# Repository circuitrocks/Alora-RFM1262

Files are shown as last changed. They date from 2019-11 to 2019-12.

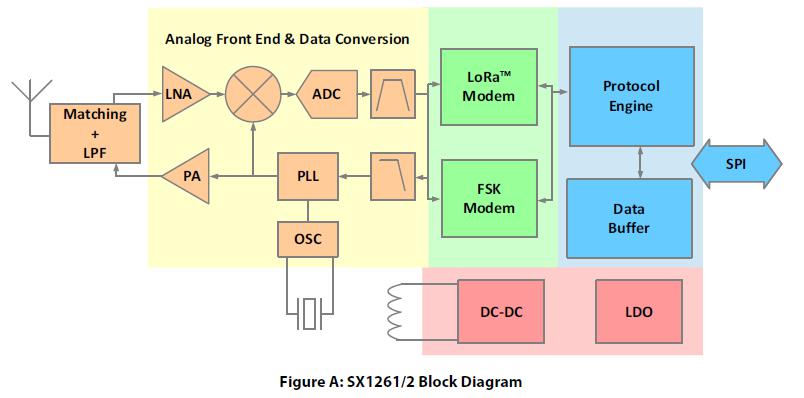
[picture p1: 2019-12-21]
Alora-RFM1262-Productsheet_html_1c7b20d6.jpg

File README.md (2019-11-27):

# Alora-RFM1262 support files for the Alora RFM1262 boards.    
This repository contains the HW and SW support files for the [Circuitrocks Alora RFM1262](https://circuit.rocks/lora) board. 

The board is compatible with the [Adafruit Feather specifications](https://learn.adafruit.com/adafruit-feather?view=all). But it is tested only with the [Adafruit Feather HUZZAH ESP8266](https://circuit.rocks/wifi-feather-huzzah-esp8266-adafruit.html) and the [Adafruit HUZZAH32 ESP32](https://circuit.rocks/huzzah32-esp32-feather-board-adafruit.html) Feathers.

## Hardware
[Eagle format schematic and PCB files](https://github.com/circuitrocks/Alora-RFM1262/tree/master/Hardware/Eagle)    
[Schematic as PDF file](https://github.com/circuitrocks/Alora-RFM1262/tree/master/Hardware)    
[3D files of the board in Autodesk Fusion 360 and STEP format](https://github.com/circuitrocks/Alora-RFM1262/tree/master/Hardware/3D)    

## Software
At the moment there are two Arduino libraries available that support the Semtech SX1262 chips.
- [RadioLib](https://github.com/jgromes/RadioLib) by Jan Gromes
- [SX126x-Arduino](https://github.com/beegee-tokyo/SX126x-Arduino) by Bernd Giesecke

Please check the ArduinoIDE or PlatformIO documentation how to install the libraries.

The first one is easier to use and supports most Arduino HW platforms.
The second one is more complicated and supports only ESP8266, ESP32 and nRF52 HW platforms. **_But it supports LoRaWan_** and it has a working example for a **_single channel LoRaWan gateway_**.

It is recommended to use the RadioLib library if you just want to do simple LoRa communication. But if you want to connect your Alora SX1262 module to LoRaWan you should choose the SX126x-Arduino library.

Examples for both libraries can be found in the folders [Using_SX1262x_Arduino](https://github.com/circuitrocks/Alora-RFM1262/tree/master/Software/Using_SX126x_Arduino) and [Using_RadioLib](https://github.com/circuitrocks/Alora-RFM1262/tree/master/Software/Using_RadioLib).    
Most examples are available for ArduinoIDE and PlatformIO. But if you are serious in programming, I strongly recommend you switch to PlatformIO as your development IDE.

- RadioLib examples
  - [RFM1262-PING](https://github.com/circuitrocks/Alora-RFM1262/tree/master/Software/Using_RadioLib/ArduinoIDE/RFM1262-PING) and [RFM1262-PONG](https://github.com/circuitrocks/Alora-RFM1262/tree/master/Software/Using_RadioLib/ArduinoIDE/RFM1262-PONG) are simple communication examples between two LoRa nodes using the RadioLib library. These examples are for ArduinoIDE.
  - [RFM1262-PING](https://github.com/circuitrocks/Alora-RFM1262/tree/master/Software/Using_RadioLib/PlatformIO/RFM1262-PING) and [RFM1262-PONG](https://github.com/circuitrocks/Alora-RFM1262/tree/master/Software/Using_RadioLib/PlatformIO/RFM1262-PONG) are simple communication examples between two LoRa nodes using the RadioLib library. These examples are for PlatformIO.
- SX126x-Arduino examples
  - [PingPong](https://github.com/circuitrocks/Alora-RFM1262/tree/master/Software/Using_SX126x_Arduino/ArduinoIDE/PingPong) is a simple communication example between two LoRa nodes using the SX126x_Arduino library with ArduinoIDE
  - [LoRaWanPio](https://github.com/circuitrocks/Alora-RFM1262/tree/master/Software/Using_SX126x_Arduino/PlatformIO/LoRaWanPio) is an example for a LoRaWan node.
  - [SX1262-SC-GW](https://github.com/circuitrocks/Alora-RFM1262/tree/master/Software/Using_SX126x_Arduino/PlatformIO/SX1262-SC-GW) is a single channel LoRaWan gateway. The code is based on the [ESP-1ch-Gateway-v6.0](https://github.com/things4u/ESP-1ch-Gateway-v6.0) single channel LoRaWan gateway. It was ported from from Semtech SX127x to Semttech SX1262 LoRa chips. More information can be found in the [readme](https://github.com/circuitrocks/Alora-RFM1262/blob/master/Software/Using_SX126x_Arduino/PlatformIO/SX1262-SC-GW/README.md) for this application.

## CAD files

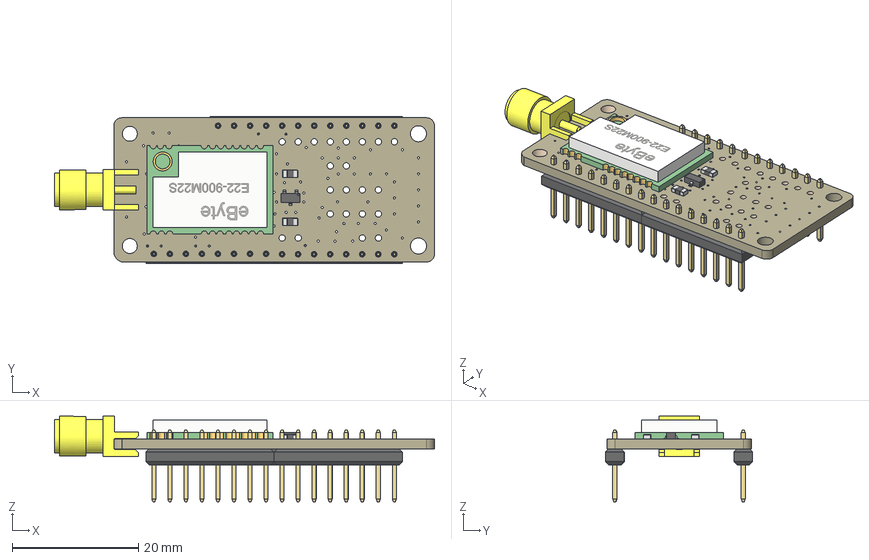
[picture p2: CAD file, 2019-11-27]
Hardware/3D/RFM1262 v5.step
60.2 x 23.4 x 13.6 mm
Board
E22-900M22S
S9013
10K
10K_1
U.FL/SMA
8p-2.54
8p-2.54_1
6p-2.54
6p-2.54_1

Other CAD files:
Hardware/3D/RFM1262 v5.f3d

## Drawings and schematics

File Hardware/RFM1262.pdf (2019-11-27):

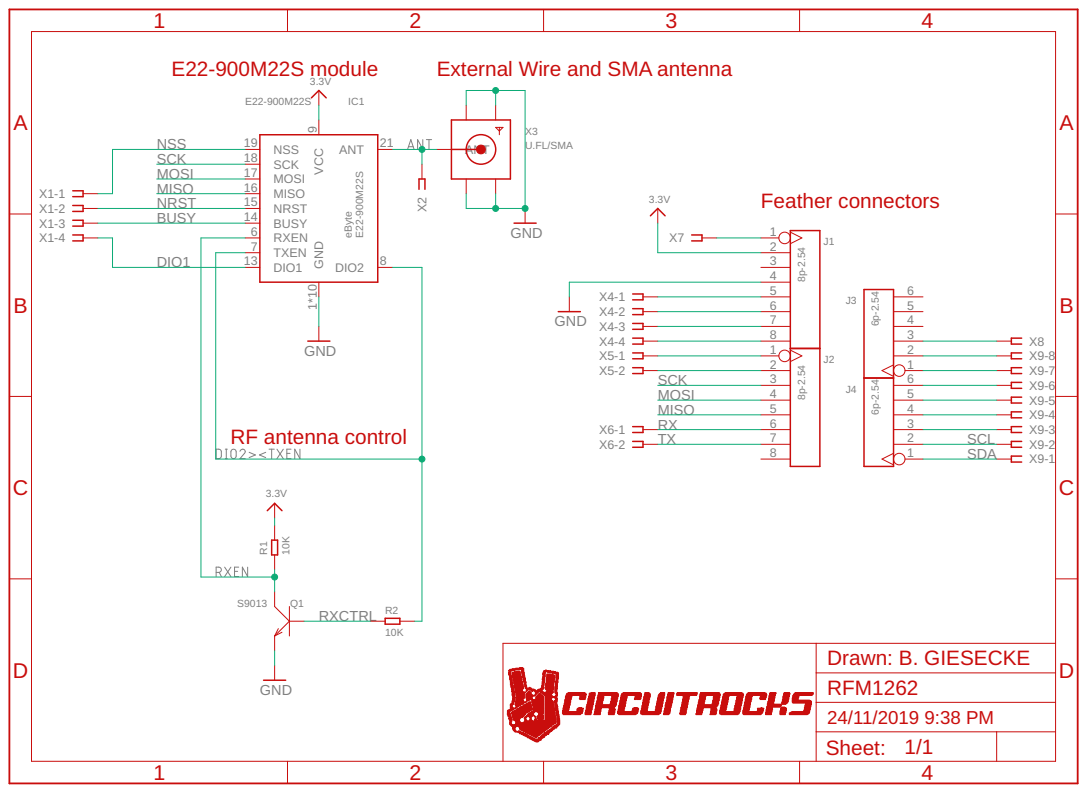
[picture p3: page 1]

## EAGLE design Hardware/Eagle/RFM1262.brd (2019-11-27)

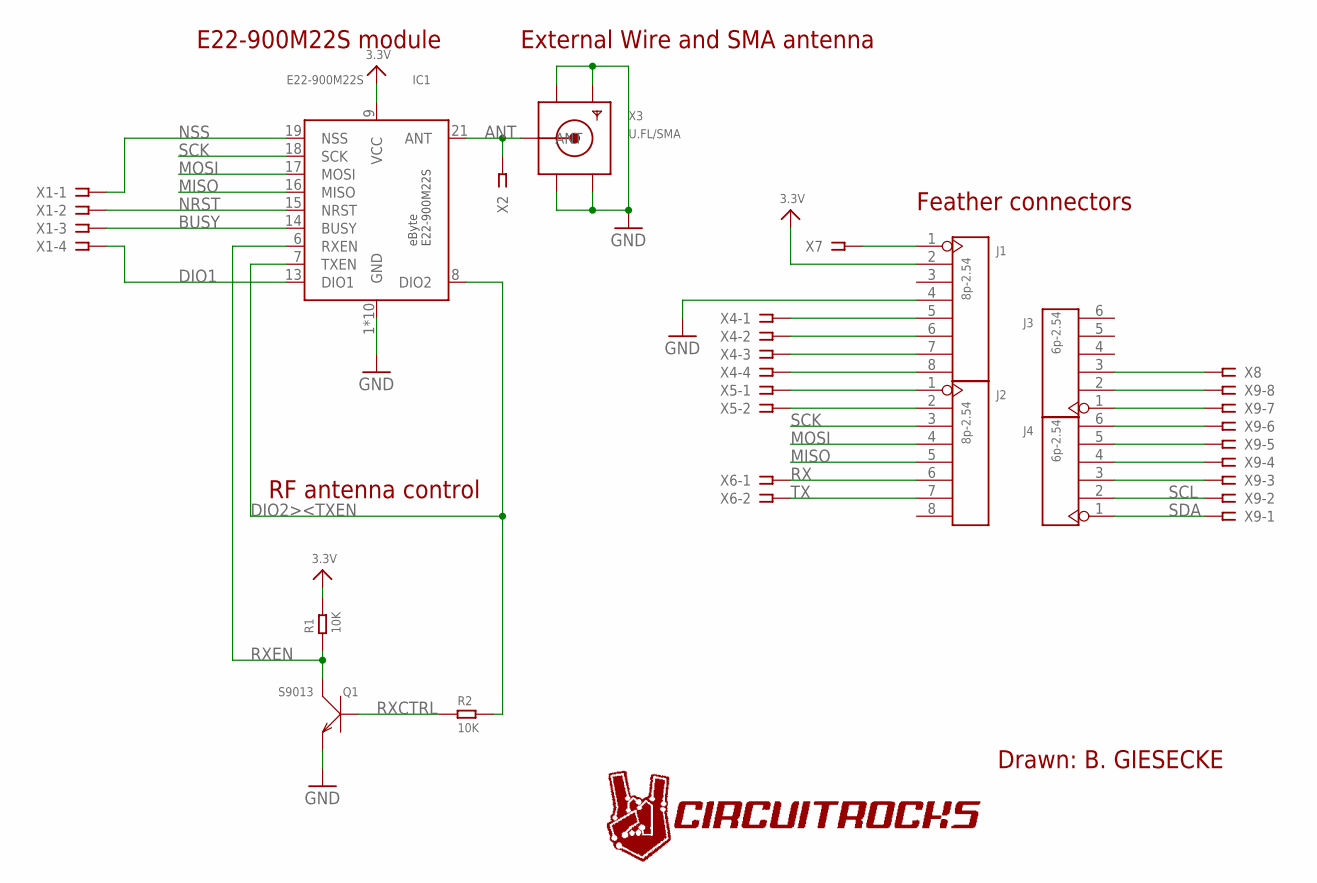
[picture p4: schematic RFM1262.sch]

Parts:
IC1: E22-900M22S
J1, J2: 8p-2.54; H8-2.54
J3, J4: 6p-2.54; H6-2.54
Q1: S9013; SOT-23
R1, R2: 10K; R0805
X1, X4: SSW-104-02-G-S
X2, X7, X8: SSW-101-02-G-S
X3: U.FL/SMA; SMA_EDGELAUNCH_UFL
X5, X6: SSW-102-02-G-S
X9: SSW-108-02-G-S

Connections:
3.3V: IC1.9 (VCC), J1.2, R1.2
ANT: IC1.21 (ANT), X2.1, X3.P (ANT)
BUSY: IC1.14 (BUSY), X1.3
DIO1: IC1.13 (DIO1), X1.4
DIO2><TXEN: IC1.7 (TXEN), IC1.8 (DIO2), R2.2
GND: IC1.1 (GND), IC1.2 (GND), IC1.3 (GND), IC1.4 (GND), IC1.5 (GND), IC1.10 (GND), IC1.11 (GND), IC1.12 (GND), IC1.20 (GND), IC1.22 (GND), J1.4, Q1.2 (E), X3.GND@1 (GND1), X3.GND@2 (GND2), X3.GND@3 (GND3), X3.GND@4 (GND4)
MISO: IC1.16 (MISO), J2.5
MOSI: IC1.17 (MOSI), J2.4
unnamed: J1.1, X7.1
unnamed: J3.3, X8.1
unnamed: J1.5, X4.1
unnamed: J1.6, X4.2
unnamed: J1.7, X4.3
unnamed: J1.8, X4.4
unnamed: J2.1, X5.1
unnamed: J2.2, X5.2
unnamed: J3.2, X9.8
unnamed: J3.1, X9.7
unnamed: J4.6, X9.6
unnamed: J4.5, X9.5
unnamed: J4.4, X9.4
unnamed: J4.3, X9.3
NRST: IC1.15 (NRST), X1.2
NSS: IC1.19 (NSS), X1.1
RX: J2.6, X6.1
RXCTRL: Q1.1 (B), R2.1
RXEN: IC1.6 (RXEN), Q1.3 (C), R1.1
SCK: IC1.18 (SCK), J2.3
SCL: J4.2, X9.2
SDA: J4.1, X9.1
TX: J2.7, X6.2

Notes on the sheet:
Drawn: B. GIESECKE
E22-900M22S module
External Wire and SMA antenna
Feather connectors
RF antenna control

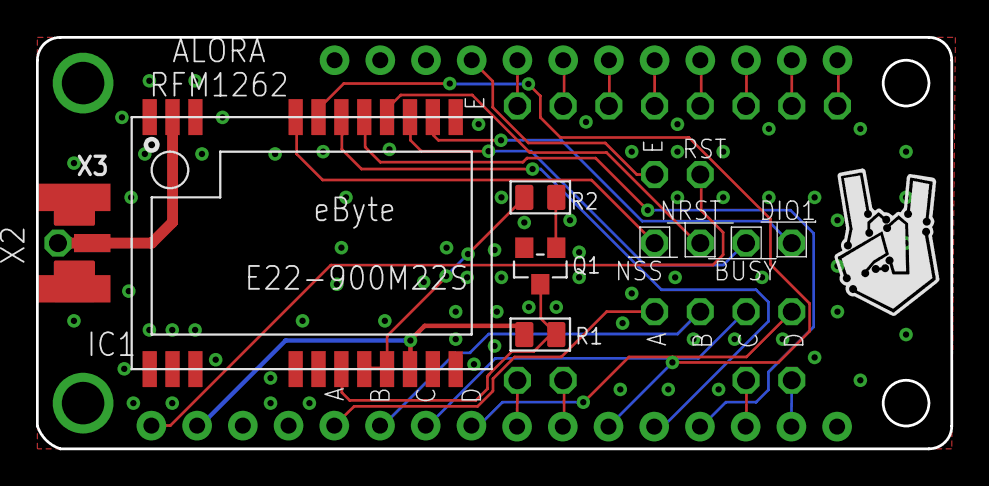
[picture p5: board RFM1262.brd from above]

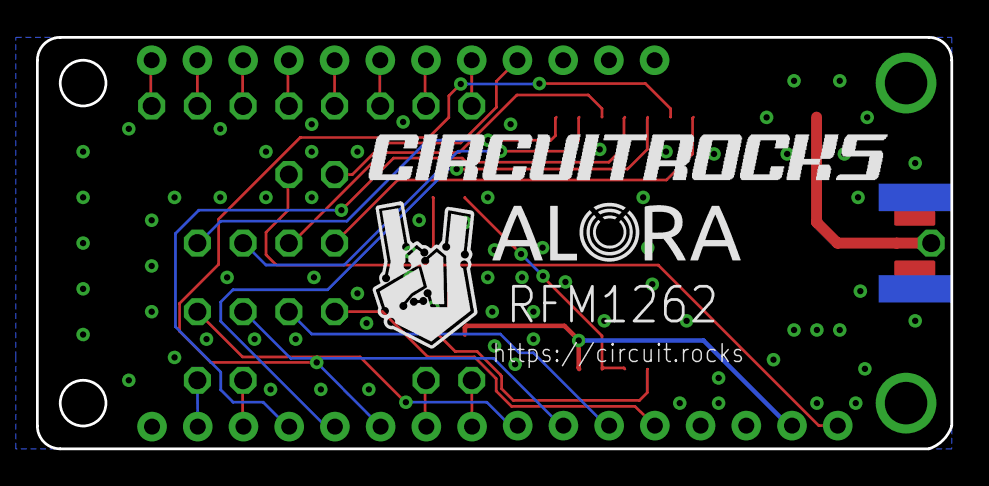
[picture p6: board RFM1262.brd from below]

Board: 2 copper layers, 50.8 x 22.9 mm, 17 parts (4 on the bottom side), 31 nets.

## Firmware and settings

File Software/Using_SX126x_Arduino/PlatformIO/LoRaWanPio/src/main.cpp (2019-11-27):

#include <Arduino.h>

#include <LoRaWan-Arduino.h>
#include <SPI.h>
#include <Ticker.h>
#ifdef ESP32
#include <WiFi.h>
#include <WiFiMulti.h>
#include <ESPmDNS.h>
#include <WiFiUdp.h>
#include <ArduinoOTA.h>
WiFiMulti wifiMulti;
#endif
#ifdef ESP8266
#include <ESP8266WiFi.h>
#include <ESP8266WiFiMulti.h>
#include <ESP8266mDNS.h>
#include <WiFiUdp.h>
#include <ArduinoOTA.h>
ESP8266WiFiMulti wifiMulti;
#endif

// #define SCHED_MAX_EVENT_DATA_SIZE APP_TIMER_SCHED_EVENT_DATA_SIZE /**< Maximum size of scheduler events. */
// #define SCHED_QUEUE_SIZE 60										  /**< Maximum number of events in the scheduler queue. */

#define LORAWAN_ADR_ON 1  /**< LoRaWAN Adaptive Data Rate enabled (the end-device should be static here). */
#define LORAWAN_ADR_OFF 0 /**< LoRaWAN Adaptive Data Rate disabled. */

#define LORAWAN_APP_DATA_BUFF_SIZE 256  /**< Size of the data to be transmitted. */
#define LORAWAN_APP_TX_DUTYCYCLE 30000 /**< Defines the application data transmission duty cycle. 30s, value in [ms]. */
#define APP_TX_DUTYCYCLE_RND 1000	  /**< Defines a random delay for application data transmission duty cycle. 1s, value in [ms]. */
#define JOINREQ_NBTRIALS 3			   /**< Number of trials for the join request. */

hw_config hwConfig;

#ifdef ESP32
#ifdef RED_BOARD
// ESP32 Elecrow Red board - SX126x pin configuration
int PIN_LORA_RESET = 4;  // LORA RESET
int PIN_LORA_NSS = 5;	// LORA SPI CS
int PIN_LORA_SCLK = 18;  // LORA SPI CLK
int PIN_LORA_MISO = 19;  // LORA SPI MISO
int PIN_LORA_DIO_1 = 26; // LORA DIO_1
int PIN_LORA_BUSY = 25;  // LORA SPI BUSY
int PIN_LORA_MOSI = 23;  // LORA SPI MOSI
uint8_t nodeDeviceEUI[8] = {0x00, 0x95, 0x64, 0x1F, 0xDA, 0x91, 0x19, 0x0B};
uint8_t nodeAppEUI[8] = {0x70, 0xB3, 0xD5, 0x7E, 0xD0, 0x02, 0x01, 0xE1};
// Only needed for OOTA registration
// uint8_t nodeAppKey[16] = {0x07, 0xC0, 0x82, 0x0C, 0x30, 0xB9, 0x08, 0x70, 0x0C, 0x0F, 0x70, 0x06, 0x00, 0xB0, 0xBE, 0x09};
uint32_t nodeDevAddr = 0x260211CE;
uint8_t nodeNwsKey[16] = {0x71, 0x6E, 0xB7, 0x65, 0x90, 0x60, 0x8F, 0xEB, 0x50, 0x24, 0xF9, 0x98, 0x31, 0x29, 0x82, 0xC8};
uint8_t nodeAppsKey[16] = {0x0B, 0x94, 0x60, 0x10, 0x8C, 0x41, 0x3C, 0x7C, 0xF8, 0xC7, 0x99, 0x14, 0x27, 0x90, 0x96, 0x92};
#define LED_ON LOW
#define LED_OFF HIGH
#elif defined WROVER_BOARD
// ESP32 Wrover black board - SX126x pin configuration
int PIN_LORA_RESET = 4;  // LORA RESET
int PIN_LORA_NSS = 5;	// LORA SPI CS
int PIN_LORA_SCLK = 18;  // LORA SPI CLK
int PIN_LORA_MISO = 19;  // LORA SPI MISO
int PIN_LORA_DIO_1 = 26; // LORA DIO_1
int PIN_LORA_BUSY = 25;  // LORA SPI BUSY
int PIN_LORA_MOSI = 23;  // LORA SPI MOSI
uint8_t nodeDeviceEUI[8] = {0x00, 0x20, 0x45, 0xB4, 0xDF, 0xF7, 0x2A, 0x33};
uint8_t nodeAppEUI[8] = {0x70, 0xB3, 0xD5, 0x7E, 0xD0, 0x02, 0x01, 0xE1};
// Only needed for OOTA registration
// uint8_t nodeAppKey[16] = {0x07, 0xC0, 0x82, 0x0C, 0x30, 0xB9, 0x08, 0x70, 0x0C, 0x0F, 0x70, 0x06, 0x00, 0xB0, 0xBE, 0x09};
uint32_t nodeDevAddr = 0x26021040;
uint8_t nodeNwsKey[16] = {0x52, 0x71, 0x0C, 0x47, 0x98, 0xD8, 0xE3, 0xE1, 0x7A, 0x40, 0x4B, 0x2C, 0x5A, 0x74, 0x00, 0xB7};
uint8_t nodeAppsKey[16] = { 0xB4, 0x0F, 0xCD, 0xD2, 0x5E, 0x2B, 0x4D, 0xBE, 0xD9, 0x92, 0x40, 0x0E, 0x6F, 0x65, 0x91, 0xB9 };
#define LED_ON LOW
#define LED_OFF HIGH
#else
// ESP32 Feather - SX126x pin configuration
int PIN_LORA_RESET = 32; //16; // LORA RESET
int PIN_LORA_DIO_1 = 14; //14; // LORA DIO_1
int PIN_LORA_BUSY = 27;  //33; // LORA SPI BUSY
int PIN_LORA_NSS = 33;   //27; // LORA SPI CS
int PIN_LORA_SCLK = 5;   // LORA SPI CLK
int PIN_LORA_MISO = 19;  // LORA SPI MISO
int PIN_LORA_MOSI = 18;  // LORA SPI MOSI
uint8_t nodeDeviceEUI[8] = {0x00, 0xE6, 0xBF, 0xFF, 0xCD, 0x42, 0x4C, 0x2B};
uint8_t nodeAppEUI[8] = {0x70, 0xB3, 0xD5, 0x7E, 0xD0, 0x02, 0x01, 0xE1};
// Only needed for OOTA registration
// uint8_t nodeAppKey[16] = {0x07, 0xC0, 0x82, 0x0C, 0x30, 0xB9, 0x08, 0x70, 0x0C, 0x0F, 0x70, 0x06, 0x00, 0xB0, 0xBE, 0x09};
uint32_t nodeDevAddr = 0x26021C92;
uint8_t nodeNwsKey[16] = {0x06, 0x52, 0x24, 0x82, 0x79, 0x75, 0xD1, 0x95, 0xF8, 0xED, 0x21, 0x84, 0x0D, 0x8A, 0xC6, 0xFD};
uint8_t nodeAppsKey[16] = {0x68, 0xE8, 0xD9, 0xC6, 0xC7, 0x79, 0x8F, 0x22, 0x2B, 0x91, 0x7E, 0xF1, 0x94, 0x34, 0x7B, 0xD9};
#define LED_ON HIGH
#define LED_OFF LOW
#endif
#endif
#ifdef ESP8266
// ESP8266 Feather - SX126x pin configuration
int PIN_LORA_RESET = -1; // 16;  // LORA RESET NOT CONNECTED !
int PIN_LORA_DIO_1 = 15; // 5;   // LORA DIO_1
int PIN_LORA_BUSY = 16; // 4;	// LORA SPI BUSY
int PIN_LORA_NSS = 0; // 15;	// LORA SPI CS
int PIN_LORA_SCLK = SCK;  // 14; // LORA SPI CLK
int PIN_LORA_MISO = MISO; // 12; // LORA SPI MISO
int PIN_LORA_MOSI = MOSI; // 13; // LORA SPI MOSI
uint8_t nodeDeviceEUI[8] = {0x00, 0xD0, 0x53, 0xDE, 0x91, 0xEF, 0xC1, 0x95};
uint8_t nodeAppEUI[8] = {0x70, 0xB3, 0xD5, 0x7E, 0xD0, 0x02, 0x01, 0xE1};
// Only needed for OOTA registration
// uint8_t nodeAppKey[16] = {0x07, 0xC0, 0x82, 0x0C, 0x30, 0xB9, 0x08, 0x70, 0x0C, 0x0F, 0x70, 0x06, 0x00, 0xB0, 0xBE, 0x09};
uint32_t nodeDevAddr = 0x260214FE;
uint8_t nodeNwsKey[16] = {0x66, 0xCE, 0xD5, 0xCD, 0x2A, 0x30, 0xC7, 0x1F, 0x34, 0x07, 0xB2, 0x58, 0x7D, 0x09, 0x64, 0x66};
uint8_t nodeAppsKey[16] = {0xAF, 0x6C, 0x9A, 0x5B, 0x08, 0x64, 0x5B, 0x1E, 0x9B, 0xAB, 0x92, 0x66, 0x3E, 0xA5, 0x43, 0x42};
#define LED_ON LOW
#define LED_OFF HIGH
#endif

#if !defined(ESP32) && !defined(ESP8266)
#error "Board not supported"
#endif

// Foward declaration
static void lorawan_has_joined_handler(void);
static void lorawan_rx_handler(lmh_app_data_t *app_data);
static void lorawan_confirm_class_handler(DeviceClass_t Class);
static void send_lora_frame(void);
static uint32_t timers_init(void);

// APP_TIMER_DEF(lora_tx_timer_id);                                              ///< LoRa tranfer timer instance.
TimerEvent_t appTimer;														  ///< LoRa tranfer timer instance.
static uint8_t m_lora_app_data_buffer[LORAWAN_APP_DATA_BUFF_SIZE];			  ///< Lora user application data buffer.
static lmh_app_data_t m_lora_app_data = {m_lora_app_data_buffer, 0, 0, 0, 0}; ///< Lora user application data structure.

/**@brief Structure containing LoRaWan parameters, needed for lmh_init()
 */
static lmh_param_t lora_param_init = {LORAWAN_ADR_OFF, DR_3, LORAWAN_PUBLIC_NETWORK, JOINREQ_NBTRIALS, LORAWAN_DEFAULT_TX_POWER};
// DR_8
// LORAWAN_DEFAULT_DATARATE
/**@brief Structure containing LoRaWan callback functions, needed for lmh_init()
*/
static lmh_callback_t lora_callbacks = {BoardGetBatteryLevel, BoardGetUniqueId, BoardGetRandomSeed,
										lorawan_rx_handler, lorawan_has_joined_handler, lorawan_confirm_class_handler};

// Check if the board has an LED port defined
#ifndef LED_BUILTIN
#ifdef ESP32
#ifdef RED_BOARD
#define LED_BUILTIN 16
#else
#define LED_BUILTIN 13
#endif
#endif
#ifdef ESP8266
#define LED_BUILTIN 0
#endif
#endif

int32_t chipTemp = 0;

Ticker ledTicker;

bool wifiFirstConnect = true;

/**@brief Setup function
 */
void ledOff(void)
{
	digitalWrite(LED_BUILTIN, LED_OFF);
}

/**@brief Setup function
 */
void setup()
{
	pinMode(LED_BUILTIN, OUTPUT);
	digitalWrite(LED_BUILTIN, LED_OFF);

	// Define the HW configuration between MCU and SX126x
	hwConfig.CHIP_TYPE = SX1262_CHIP;		  // Example uses an eByte E22 module with an SX1262
	hwConfig.PIN_LORA_RESET = PIN_LORA_RESET; // LORA RESET
	hwConfig.PIN_LORA_NSS = PIN_LORA_NSS;	 // LORA SPI CS
	hwConfig.PIN_LORA_SCLK = PIN_LORA_SCLK;   // LORA SPI CLK
	hwConfig.PIN_LORA_MISO = PIN_LORA_MISO;   // LORA SPI MISO
	hwConfig.PIN_LORA_DIO_1 = PIN_LORA_DIO_1; // LORA DIO_1
	hwConfig.PIN_LORA_BUSY = PIN_LORA_BUSY;   // LORA SPI BUSY
	hwConfig.PIN_LORA_MOSI = PIN_LORA_MOSI;   // LORA SPI MOSI
	hwConfig.RADIO_TXEN = -1;				  // LORA ANTENNA TX ENABLE
	hwConfig.RADIO_RXEN = -1;				  // LORA ANTENNA RX ENABLE
	hwConfig.USE_DIO2_ANT_SWITCH = true;	  // Example uses an CircuitRocks Alora RFM1262 which uses DIO2 pins as antenna control
	hwConfig.USE_DIO3_TCXO = true;			  // Example uses an CircuitRocks Alora RFM1262 which uses DIO3 to control oscillator voltage
	hwConfig.USE_DIO3_ANT_SWITCH = false;	 // Only Insight ISP4520 module uses DIO3 as antenna control

	// Initialize Serial for debug output
	Serial.begin(115200);

	Serial.println("=====================================");
	Serial.println("SX126x LoRaWan test");
	Serial.printf("Node %X\n", nodeDevAddr);
	Serial.println("=====================================");

	// Start WiFi so we can do OTA from here
	wifiMulti.addAP("MHC2", "teresa1963");
	wifiMulti.addAP("MHC", "teresa1963");

	wifiMulti.run();

	// Initialize Scheduler and timer
	uint32_t err_code = timers_init();
	if (err_code != 0)
	{
		Serial.printf("timers_init failed - %d\n", err_code);
	}

	// Initialize LoRa chip.
	err_code = lora_hardware_init(hwConfig);
	if (err_code != 0)
	{
		Serial.printf("lora_hardware_init failed - %d\n", err_code);
	}

	// Setup the EUIs and Keys
	lmh_setDevEui(nodeDeviceEUI);
	lmh_setAppEui(nodeAppEUI);
	// lmh_setAppKey(nodeAppKey); // Only needed for OOTA registration
	lmh_setNwkSKey(nodeNwsKey);
	lmh_setAppSKey(nodeAppsKey);
	lmh_setDevAddr(nodeDevAddr);

	// #ifndef RED_BOARD
	// 	// Setup connection to a single channel gateway
	// 	lmh_setSingleChannelGateway(0, DR_3);
	// #endif

	// Initialize LoRaWan
	err_code = lmh_init(&lora_callbacks, lora_param_init);
	if (err_code != 0)
	{
		Serial.printf("lmh_init failed - %d\n", err_code);
	}

	// For some regions we might need to define the sub band the gateway is listening to
	/// \todo This is for Dragino LPS8 gateway. How about other gateways???
	if (!lmh_setSubBandChannels(1))
	{
		Serial.println("lmh_setSubBandChannels failed. Wrong sub band requested?");
	}

	// Start Join procedure
	lmh_join();
}

/**@brief Main loop
 */
void loop()
{
	// Handle Radio events
	Radio.IrqProcess();

#ifndef ESP8266
	if (wifiFirstConnect && WiFi.isConnected())
	{
		// Start OTA now
		wifiFirstConnect = false;

		ArduinoOTA.begin();

#ifdef ESP32
#ifdef RED_BOARD
		ArduinoOTA.setHostname("ESP32_R");
#else
		ArduinoOTA.setHostname("ESP32_F");
#endif
#else
		ArduinoOTA.setHostname("ESP82_F");
#endif
		ArduinoOTA.onStart([]() {
			String type;
			// NOTE: if updating FS this would be the place to unmount FS using FS.end()
			Serial.println("Start updating");
		});
		ArduinoOTA.onEnd([]() {
			Serial.println("\nEnd");
		});
		ArduinoOTA.onProgress([](unsigned int progress, unsigned int total) {
			Serial.printf("Progress: %u%%\r", (progress / (total / 100)));
		});

		ArduinoOTA.begin();
	}
	wifiMulti.run();
#endif
	// We are on FreeRTOS, give other tasks a chance to run
	// delay(100);
}

/**@brief LoRa function for handling HasJoined event.
 */
static void lorawan_has_joined_handler(void)
{
#if (OVER_THE_AIR_ACTIVATION != 0)
	Serial.println("Network Joined");
#else
	Serial.println("OVER_THE_AIR_ACTIVATION != 0");

#endif
	lmh_class_request(CLASS_A);

	TimerSetValue(&appTimer, LORAWAN_APP_TX_DUTYCYCLE);
	TimerStart(&appTimer);
	// app_timer_start(lora_tx_timer_id, APP_TIMER_TICKS(LORAWAN_APP_TX_DUTYCYCLE), NULL);
	Serial.println("Sending frame");
	send_lora_frame();
}

/**@brief Function for handling LoRaWan received data from Gateway
 *
 * @param[in] app_data  Pointer to rx data
 */
static void lorawan_rx_handler(lmh_app_data_t *app_data)
{
	Serial.printf("LoRa Packet received on port %d, size:%d, rssi:%d, snr:%d\n",
				  app_data->port, app_data->buffsize, app_data->rssi, app_data->snr);

	for (int i = 0; i < app_data->buffsize; i++)
	{
		Serial.printf("%0X ", app_data->buffer[i]);
	}
	Serial.println("");

	switch (app_data->port)
	{
	case 3:
		// Port 3 switches the class
		if (app_data->buffsize == 1)
		{
			switch (app_data->buffer[0])
			{
			case 0:
				lmh_class_request(CLASS_A);
				break;

			case 1:
				lmh_class_request(CLASS_B);
				break;

			case 2:
				lmh_class_request(CLASS_C);
				break;

			default:
				break;
			}
		}
		break;

	case LORAWAN_APP_PORT:
		// YOUR_JOB: Take action on received data
		break;

	default:
		break;
	}
}

/**@brief Function to confirm LORaWan class switch.
 *
 * @param[in] Class  New device class
 */
static void lorawan_confirm_class_handler(DeviceClass_t Class)
{
	Serial.printf("switch to class %c done\n", "ABC"[Class]);

	// Informs the server that switch has occurred ASAP
	m_lora_app_data.buffsize = 0;
	m_lora_app_data.port = LORAWAN_APP_PORT;
	lmh_send(&m_lora_app_data, LMH_UNCONFIRMED_MSG);
}

/**@brief Function for sending a LoRa package.
 */
static void send_lora_frame(void)
{
	if (lmh_join_status_get() != LMH_SET)
	{
		//Not joined, try again later
		Serial.println("Did not join network, skip sending frame");
		return;
	}

	uint32_t i = 0;
	char t100 = (char)(chipTemp / 100);
	char t10 = (char)((chipTemp - (t100 * 100)) / 10);
	char t1 = (char)((chipTemp - (t100 * 100) - (t10 * 10)) / 1);
	m_lora_app_data.port = LORAWAN_APP_PORT;

	m_lora_app_data.buffer[i++] = '{';
	m_lora_app_data.buffer[i++] = '"';
	m_lora_app_data.buffer[i++] = 'i';
	m_lora_app_data.buffer[i++] = '"';
	m_lora_app_data.buffer[i++] = ':';
	// m_lora_app_data.buffer[i++] = '\"';
	// m_lora_app_data.buffer[i++] = 'E';
	// m_lora_app_data.buffer[i++] = 'S';
	// m_lora_app_data.buffer[i++] = 'P';
#ifdef ESP32
#ifdef RED_BOARD
	m_lora_app_data.buffer[i++] = '0';
	// m_lora_app_data.buffer[i++] = '3';
	// m_lora_app_data.buffer[i++] = '2';
	// m_lora_app_data.buffer[i++] = 'R';
#else
	m_lora_app_data.buffer[i++] = '1';
	// m_lora_app_data.buffer[i++] = '3';
	// m_lora_app_data.buffer[i++] = '2';
#endif
#else
	m_lora_app_data.buffer[i++] = '2';
	// m_lora_app_data.buffer[i++] = '8';
	// m_lora_app_data.buffer[i++] = '6';
#endif
	m_lora_app_data.buffer[i++] = ',';
	m_lora_app_data.buffer[i++] = '"';
	m_lora_app_data.buffer[i++] = 'n';
	m_lora_app_data.buffer[i++] = '"';
	m_lora_app_data.buffer[i++] = ':';
	// m_lora_app_data.buffer[i++] = ' ';
	m_lora_app_data.buffer[i++] = t100 + 0x30;
	m_lora_app_data.buffer[i++] = t10 + 0x30;
	m_lora_app_data.buffer[i++] = t1 + 0x30;
	m_lora_app_data.buffer[i++] = '}';
	m_lora_app_data.buffsize = i;

	Serial.print("Data: ");
	Serial.println((char *)m_lora_app_data.buffer);
	Serial.print("Size: ");
	Serial.println(m_lora_app_data.buffsize);
	Serial.print("Port: ");
	Serial.println(m_lora_app_data.port);

	chipTemp += 1;
	if (chipTemp >= 999)
		chipTemp = 0;

	lmh_error_status error = lmh_send(&m_lora_app_data, LMH_UNCONFIRMED_MSG);
	if (error == LMH_SUCCESS)
	{
	}
	Serial.printf("lmh_send result %d\n", error);
	digitalWrite(LED_BUILTIN, LED_ON);
	ledTicker.once(1, ledOff);
}

/**@brief Function for handling a LoRa tx timer timeout event.
 */
static void tx_lora_periodic_handler(void)
{
	TimerSetValue(&appTimer, LORAWAN_APP_TX_DUTYCYCLE);
	TimerStart(&appTimer);
	Serial.println("Sending frame");
	send_lora_frame();
}

/**@brief Function for the Timer initialization.
 *
 * @details Initializes the timer module. This creates and starts application timers.
 */
static uint32_t timers_init(void)
{
	appTimer.timerNum = 3;
	TimerInit(&appTimer, tx_lora_periodic_handler);
	return 0;
}

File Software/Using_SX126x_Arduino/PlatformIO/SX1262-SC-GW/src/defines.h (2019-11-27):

// 1-channel LoRa Gateway for ESP8266 / ESP32
// Copyright (c) 2016, 2017, 2018, 2019 Maarten Westenberg version for ESP8266
// Version 6.1.0 E EU868
// Date: 2019-10-20
//
// Based on work done by Thomas Telkamp for Raspberry PI 1ch gateway and many others.
// Contibutions of Dorijan Morelj and Andreas Spies for OLED support.
//
// All rights reserved. This program and the accompanying materials
// are made available under the terms of the MIT License
// which accompanies this distribution, and is available at
// https://opensource.org/licenses/mit-license.php
//
// NO WARRANTY OF ANY KIND IS PROVIDED
//
// Author: Maarten Westenberg (mw12554@hotmail.com)
//
// ********************************************************************************
// ********************************************************************************
// Ported to use with Semtech SX1262 chips
// Author: Bernd Giesecke (https://github.com/beegee-tokyo)
//
// Port is work in progress
// CAD and HOP is not supported for SX1262 chips
// Downlink is not working
// Compiles under PlatformIO only
// ********************************************************************************
// ********************************************************************************
//
// This file contains a number of compile-time settings that can be set on (=1) or off (=0)
// The disadvantage of compile time is minor compared to the memory gain of not having
// too much code compiled and loaded on your ESP8266.
//
// ----------------------------------------------------------------------------------------

// NOTE: Compile with ESP32 setting and board "ESP32 Dev Module" or "Heltec WiFi Lora 32"
#define VERSION "V.6.1.0.E.US915; 191020a"

// This value of DEBUG determines whether some parts of code get compiled.
// Also this is the initial value of debug parameter.
// The value can be changed using the admin webserver
// For operational use, set initial DEBUG vaulue 0
#define DEBUG 2

// Debug message will be put on Serial is this one is set.
// If set to 0, not USB Serial prints are done
// Set to 1 it will prinr all user level messages (with correct debug set)
// If set to 2 it will also print interrupt messages (not recommended)
#define DUSB 1

// Define whether we should do a formatting of SPIFFS when starting the gateway
// This is usually a good idea if the webserver is interrupted halfway a writing
// operation. Also to be used when software is upgraded
// Normally, value 0 is a good default.
#define _SPIFF_FORMAT 0

// Define the frequency band the gateway will listen on. Valid options are
// EU863_870 (Europe), US902_928 (North America) & AU925_928 (Australia), CN470_510 (China).
// See https://www.thethingsnetwork.org/docs/lorawan/frequency-plans.html
// #define EU863_870 1
#define US902_928 1
// #define AU925_928 1
// #define CN470_510 1

// Define whether to use the old Semtech gateway API, which is still supported by TTN,
// but is more lightweight than the new TTN tcp based protocol.
// NOTE: Only one of the two should be defined!
//
#define _UDPROUTER 1
// #define _TTNROUTER 1

// The spreading factor is the most important parameter to set for a single channel
// gateway. It specifies the speed/datarate in which the gateway and node communicate.
// As the name says, in principle the single channel gateway listens to one channel/frequency
// and to one spreading factor only.
// This parameters contains the default value of SF, the actual version can be set with
// the webserver and it will be stored in SPIFF
// NOTE: The frequency is set in the loraModem.h file and is default 868.100000 MHz.
#define _SPREADING SF7

// Channel Activity Detection
// This function will scan for valid LoRa headers and determine the Spreading
// factor accordingly. If set to 1 we will use this function which means the
// 1-channel gateway will become even more versatile. If set to 0 we will use the
// continuous listen mode.
// Using this function means that we HAVE to use more dio pins on the RFM95/sx1276
// device and also connect enable dio1 to detect this state.
#define _CAD 0

// Definitions for the admin webserver.
// A_SERVER determines whether or not the admin webpage is included in the sketch.
// Normally, leave it in!
#define A_SERVER 1		 // Define local WebServer only if this define is set
#define A_REFRESH 1		 // Allow the webserver refresh or not?
#define A_SERVERPORT 80  // Local webserver port (normally 80)
#define A_MAXBUFSIZE 192 // Must be larger than 128, but small enough to work

// Definitions for over the air updates. At the moment we support OTA with IDE
// Make sure that tou have installed Python version 2.7 and have Bonjour in your network.
// Bonjour is included in iTunes (which is free) and OTA is recommended to install
// the firmware on your router witout having to be really close to the gateway and
// connect with USB.
#define A_OTA 1
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

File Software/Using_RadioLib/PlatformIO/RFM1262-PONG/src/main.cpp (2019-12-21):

#include <Arduino.h>
#include <RadioLib.h>
#include <Wire.h>

#if defined(__AVR_ATmega32U4__)
/*********************************************************************/
/*********************************************************************/
/* Pin definitions for Adafruit Feather 32u4 Basic Proto             */
/*********************************************************************/
/*********************************************************************/
// Change this to the GPIO connected to the RFM1262 NSS pin
#define RFM1262_NSS 5 // Default SPI CS
// Change this to the GPIO connected to the RFM1262 DIO1 pin
#define RFM1262_DIO1 0 // RxD
// Change this to the GPIO connected to the RFM1262 BUSY pin
#define RFM1262_BUSY 1 // TxD
// Change this to the GPIO connected to the RFM1262 RST pin
#define RFM1262_RST 11 // GPIO 11
#pragma message("Building for AVR 32U4!")
#elif defined (ESP8266)
/*********************************************************************/
/*********************************************************************/
/* Pin definitions for Adafruit Feather HUZZAH with ESP8266          */
/*********************************************************************/
/*********************************************************************/
// Change this to the GPIO connected to the RFM1262 NSS pin
#define RFM1262_NSS 2 // GPIO 2
// Change this to the GPIO connected to the RFM1262 DIO1 pin
#define RFM1262_DIO1 15 // GPIO 15
// Change this to the GPIO connected to the RFM1262 BUSY pin
#define RFM1262_BUSY 13 // GPIO 13
// Change this to the GPIO connected to the RFM1262 RST pin
#define RFM1262_RST 16 // GPIO 16
#pragma message("Building for ESP8266!")
#elif defined (ESP32)
/*********************************************************************/
/*********************************************************************/
/* Pin definitions for Adafruit HUZZAH32 ESP32 Feather board         */
/*********************************************************************/
/*********************************************************************/
// Change this to the GPIO connected to the RFM1262 NSS pin
#define RFM1262_NSS 33 // Default SPI CS
// Change this to the GPIO connected to the RFM1262 DIO1 pin
#define RFM1262_DIO1 14 // GPIO 6
// Change this to the GPIO connected to the RFM1262 BUSY pin
#define RFM1262_BUSY 27 // GPIO 9
// Change this to the GPIO connected to the RFM1262 RST pin
#define RFM1262_RST 32 // GPIO 13
#pragma message("Building for ESP32!")
#elif defined (__AVR_ATmega328P__)
/*********************************************************************/
/*********************************************************************/
/* Pin definitions for Adafruit Feather 328P                         */
/*********************************************************************/
/*********************************************************************/
// Change this to the GPIO connected to the RFM1262 NSS pin
#define RFM1262_NSS 5 // Default SPI CS
// Change this to the GPIO connected to the RFM1262 DIO1 pin
#define RFM1262_DIO1 2 // GPIO 2 - IRQ0
// Change this to the GPIO connected to the RFM1262 BUSY pin
#define RFM1262_BUSY 4 // GPIO 4
// Change this to the GPIO connected to the RFM1262 RST pin
#define RFM1262_RST 6 // GPIO 6
#pragma message("Building for AVR Mega 328!")
#elif defined (SAMD_SERIES)
/*********************************************************************/
/*********************************************************************/
/* Pin definitions for Adafruit Feather M0                           */
/*********************************************************************/
/*********************************************************************/
// Change this to the GPIO connected to the RFM1262 NSS pin
#define RFM1262_NSS 5 // Default SPI CS
// Change this to the GPIO connected to the RFM1262 DIO1 pin
#define RFM1262_DIO1 6 // GPIO 6
// Change this to the GPIO connected to the RFM1262 BUSY pin
#define RFM1262_BUSY 9 // GPIO 9
// Change this to the GPIO connected to the RFM1262 RST pin
#define RFM1262_RST 13 // GPIO 13
#pragma message("Building for SAMD!")
#elif defined(NRF52832)
/*********************************************************************/
/*********************************************************************/
/* Pin definitions for Adafruit Feather nRF52 Bluefruit LE nRF52832  */
/*********************************************************************/
/*********************************************************************/
// Change this to the GPIO connected to the RFM1262 NSS pin
#define RFM1262_NSS 27  // GPIO 27
// Change this to the GPIO connected to the RFM1262 DIO1 pin
#define RFM1262_DIO1 30 // GPIO 30
// Change this to the GPIO connected to the RFM1262 BUSY pin
#define RFM1262_BUSY 31 // GPIO 31
// Change this to the GPIO connected to the RFM1262 RST pin
#define RFM1262_RST 11  // GPIO 11
#pragma message("Building for nRF52832!")
#elif defined(NRF52840)
/*********************************************************************/
/*********************************************************************/
/* Pin definitions for Adafruit Feather nRF52840 Express             */
/*********************************************************************/
/*********************************************************************/
// Change this to the GPIO connected to the RFM1262 NSS pin
#define RFM1262_NSS 5  // Pin 5 P1.08
// Change this to the GPIO connected to the RFM1262 DIO1 pin
#define RFM1262_DIO1 6 // Pin 6 P0.07
// Change this to the GPIO connected to the RFM1262 BUSY pin
#define RFM1262_BUSY 9 // Pin 9 P0.26
// Change this to the GPIO connected to the RFM1262 RST pin
#define RFM1262_RST 10 // Pin 10 P0.27
#pragma message("Building for nRF52840!")
#else
#pragma message("Unsupported platform!")
#error Select supported platform.
#endif

#ifdef ESP32
// ESP32 SPI class
SPIClass *loraSPI = new SPIClass(VSPI);
// SX1262 class
//                      NSS DIO1 DIO2 BUSY
SX1262 lora = new Module(RFM1262_NSS, RFM1262_DIO1, -1, RFM1262_BUSY, *loraSPI);
#else
// SX1262 class
//                      NSS DIO1 DIO2 BUSY
SX1262 lora = new Module(RFM1262_NSS, RFM1262_DIO1, -1, RFM1262_BUSY);
#endif

// The Ping message will be sent by the node
char pingMsg[] = "PING";
// The Pong message will be sent by the gateway
char pongMsg[] = "PONG";
// Tracks the time stamp of last packet received
long timeSinceLastPacket = 0;

// For AVR chips
#define time_t unsigned long
#ifndef LED_BUILTIN
#define LED_BUILTIN 13
#endif
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
